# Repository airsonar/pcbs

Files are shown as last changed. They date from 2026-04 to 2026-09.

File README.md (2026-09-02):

<!--
SPDX-FileCopyrightText: AirSonar contributors
SPDX-License-Identifier: CERN-OHL-W-2.0
-->

# AirSonar PCBs

This repository contains designs for PCBs used with the AirSonar project.

## Licensing

The designs and documentation for the circuit boards in this repository are licensed
under the [CERN Open Hardware Licence Version 2 - Weakly Reciprocal][CERNOHL] license
(SPDX code [CERN-OHL-W-2.0][SPDX]). The weakly reciprocal version requires that if you
modify the designs, you release them under an open license. Incorporating the designs
into a larger project does not require that project to be openly licensed (though we
would obviously encourage you to!).

[CERNOHL]: https://gitlab.com/ohwr/project/cernohl/-/wikis/Documents/CERN-OHL-version-2
[SPDX]: https://spdx.org/licenses/CERN-OHL-W-2.0.html

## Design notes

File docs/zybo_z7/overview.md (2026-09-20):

---
SPDX-FileCopyrightText: AirSonar contributors
SPDX-License-Identifier: CERN-OHL-W-2.0
---

# Zybo Z7 ARM/FPGA development board

The [Digilent Zybo Z7][zybo-z7] is a development board based around the [AMD (formerly
Xilinx) Zynq-7000][zynq-7000] system-on-a-chip (SoC). The Zynq-7000 combines a dual-core
ARM Cortex-A9 processor with a Artix-7 FPGA logic. These communicate over standard
[AXI][] communication buses, allowing custom peripherals to be designed in the
programmable logic to communicate with the processor. For the AirSonar project, this
allows many PDM microphones to be simultaneously handled in programmable logic with the
captured data being transferred to processor memory for subsequent processing and
transfer to the client.

The development board contains a number of peripherals, including gigabit Ethernet and a
Analog Devices SSM2603 audio codec outputting to a standard 3.5mm audio jack. It also
has a number of [Pmod connectors][Pmod] allowing custom circuits to be connected to the
development board.

Note that there are two variants of the Zybo Z7, the -10 and -20. These correspond to
different variants of the Zync-700, and the -10 variant has one fewer PMOD connector.
The designs in this repository are tested with the -20 variant but should be usable with
the -10.

[AXI]: https://en.wikipedia.org/wiki/Advanced_eXtensible_Interface
[Pmod]: https://en.wikipedia.org/wiki/Pmod_Interface
[zybo-z7]: https://digilent.com/reference/programmable-logic/zybo-z7/start
[zynq-7000]: https://www.amd.com/en/products/adaptive-socs-and-fpgas/soc/zynq-7000.html

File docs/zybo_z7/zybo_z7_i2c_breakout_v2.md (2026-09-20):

---
SPDX-FileCopyrightText: AirSonar contributors
SPDX-License-Identifier: CERN-OHL-W-2.0
---

# Zybo Z7 I2C breakout (v2)

The JF Pmod connector (at the left edge of the Zybo Z7 when looking at the top) connects
to a number of GPIO lines from the ARM processor. This includes two [I2C][]
communication buses, I2C0 and I2C1. This PCB acts as a breakout board to connect a
number of devices to each bus.

There are four 4-pin IDC connectors (each with 3.3V, ground, clock and data lines)
connected to I2C0. As marked on the silkscreen, these are intended for communicating
with motor drivers. There are ten 4-pin connectors connected to I2C1, intended for
auxiliary sensors such as temperature sensors. Note that the actual use of the two buses
depend on the software running on the processor; the labels on the silkscreen are only
indicative of the original intent when the circuit was designed.

As the Zynq-7000 I2C lines are only rated to 3.3V, both sets of clock and data lines
have Schottky diodes for overvoltage protection if the connected devices use higher
voltages. The design also includes a power LED and a 2x6 surface mount IDC connector
which duplicates the Pmod layout allowing for testing or further development with other
GPIO lines.

[I2C]: https://en.wikipedia.org/wiki/I2C

## Design

The schematic and PCB layout were performed using the [KiCad][] design suite. If you
want the design files, it is recommended you clone the Git repository and access them
from there. A copy of the design files and associated libraries, templates etc as they
were when this documentation was built can be
```genzip
output: airsonar_zybo_z7_i2c_breakout_v2.zip
link_text: downloaded as a zipfile
%%%
directory: libraries
directory: templates
file: zybo_z7/i2c_breakout_v2/zybo_z7_i2c_breakout_v2.kicad_pro
file: zybo_z7/i2c_breakout_v2/zybo_z7_i2c_breakout_v2.kicad_sch
file: zybo_z7/i2c_breakout_v2/zybo_z7_i2c_breakout_v2.kicad_pcb
file: zybo_z7/i2c_breakout_v2/fp-lib-table
file: zybo_z7/i2c_breakout_v2/sym-lib-table
file: zybo_z7/i2c_breakout_v2/REUSE.toml
```
if you prefer.

A
```kipdf
output: airsonar_zybo_z7_i2c_breakout_v2.pdf
link_text: PDF of the schematics and PCB layout
%%%
source: zybo_z7/i2c_breakout_v2/zybo_z7_i2c_breakout_v2.kicad_sch
--no-background-color
%%%
source: zybo_z7/i2c_breakout_v2/zybo_z7_i2c_breakout_v2.kicad_pcb
--layers
F.Cu,F.Silkscreen,Edge.Cuts
--scale
0
%%%
source: zybo_z7/i2c_breakout_v2/zybo_z7_i2c_breakout_v2.kicad_pcb
--layers
B.Cu,B.Silkscreen,Edge.Cuts
--scale
0
```
is also available. Again, this is the status of the design when this documentation was
built. The first page contains the schematic, the second page the copper and silkscreen
for the top layer, and the third page the copper and silkscreen for the bottom layer.

### Bill of materials

The following table lists the components needed to fully populate a single copy of the
PCB.  The prices given are to purchase the exact quantity needed for one PCB from
DigiKey (using the German storefront) as of 20 September 2026. Prices at other suppliers
will differ, using other component variants will change the cost, and buying larger
quantities will typically reduce the unit cost. Note that the cost of the ribbon cable
and IDC crimp connectors is not included.

Component | Description                      | Quantity | Cost
----------|----------------------------------|----------|------
C1        | 10µF 0603 ceramic capacitor      | 1        | [€0.33][dkc1]
C2-C14    | 100nF 0603 ceramic capacitor     | 13       | [€0.38][dkc2]
D1        | Orange LED (0603 package)        | 1        | [€0.21][dkd1]
D2-D5     | Schottky diode                   | 4        | [€0.84][dkd2]
J1-J14    | Through-hole 2x2 IDC header      | 14       | [€8.86][dkj1]
JF1       | Right-angle 2x6 edge connector   | 1        | [€0.92][dkjf1]
JF2       | Surface-mount 2x6 IDC header     | 1        | [€2.88][dkjf2]
R1        | 330Ω 0603 resistor               | 1        | [€0.10][dkr1]
R2-R5     | 33Ω 1/3W 0603 resistor           | 4        | [€0.52][dkr2]
          | **Total**                        |          | €15.04

[dkc1]: https://www.digikey.de/de/products/detail/cal-chip-electronics-inc/GMC10X5R106M25NT/18151144
[dkc2]: https://www.digikey.de/de/products/detail/samsung-electro-mechanics/CL10B104KB8NNND/22313108
[dkd1]: https://www.digikey.de/de/products/detail/harvatek-corporation/B1931UD-05D000314U1930/15861266
[dkd2]: https://www.digikey.de/en/products/detail/onsemi/BAT43XV2/2241875
[dkj1]: https://www.digikey.de/en/products/detail/amphenol-cs-fci/75869-130LF/1523859
[dkjf1]: https://www.digikey.de/en/products/detail/amphenol-cs-fci/10129382-912002BLF/7916140
[dkjf2]: https://www.digikey.de/de/products/detail/samtec-inc/HTST-106-01-L-DV/8473802
[dkr1]: https://www.digikey.de/de/products/detail/te-connectivity-passive-product/CRGH0603F330R/5586961
[dkr2]: https://www.digikey.de/en/products/detail/rohm-semiconductor/ESR03EZPJ330/1983466

<!-- component and software links -->

[KiCad]: https://www.kicad.org/

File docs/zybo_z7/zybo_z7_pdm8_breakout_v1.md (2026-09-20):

---
SPDX-FileCopyrightText: AirSonar contributors
SPDX-License-Identifier: CERN-OHL-W-2.0
---

# Zybo Z7 PDM8 microphone array breakout (v1)

The Pmod connectors at the bottom of the Zybo Z7 (when viewed from the top side) connect
to various IO lines from the FPGA part of the Zynq-7000. These allow custom hardware to
be connected to the FPGA. This PCB acts as a breakout board to connect multiple [PDM8
microphone arrays](../microphone_array/airsonar_pdm8_v1.md) to the FPGA.

When connected to a Zybo Z7-20 variant, up to eight microphone arrays can be connected.
These are configured in a dual-edge mode with two microphones connected to each FPGA IO
pin, outputting data on alternate clock edges. One of the FPGA IO lines is used to
provide the clock to the microphones, leaving 31 pins available for input and thus a
maximum of 62 microphones can be read. The Zybo Z7-10 variant does not include the JB
Pmod connector. This reduces the available input pins to 23 for a maximum of 46
microphones.

The breakout includes a [LMK1C1108PWR][] clock buffer to duplicate the clock signal for
each connector. This avoids adding too much load to the FPGA IO providing the clock.

The breakout also includes a power LED and duplicates of each Pmod connector for
debugging or further development.

!!! Warning
    The connector footprint for the Pmod duplicates (the bottom row of connectors) is
    the same footprint as for the array connectors. However, it is not pin compatible
    with the array connectors; plugging a microphone array into the Pmod duplicate will
    short the power supply. Although the Zybo Z7 appears to handle and recover from
    this, it is recommended that these connectors only be populated if needed, or that a
    different style of connector is used to avoid accidental connections.

## Design

The schematic and PCB layout were performed using the [KiCad][] design suite. If you
want the design files, it is recommended you clone the Git repository and access them
from there. A copy of the design files and associated libraries, templates etc as they
were when this documentation was built can be
```genzip
output: airsonar_zybo_z7_pdm8_breakout_v1.zip
link_text: downloaded as a zipfile
%%%
directory: libraries
directory: templates
file: zybo_z7/pdm8_breakout_v1/zybo_z7_pdm8_breakout_v1.kicad_dru
file: zybo_z7/pdm8_breakout_v1/zybo_z7_pdm8_breakout_v1.kicad_pro
file: zybo_z7/pdm8_breakout_v1/zybo_z7_pdm8_breakout_v1.kicad_sch
file: zybo_z7/pdm8_breakout_v1/zybo_z7_pdm8_breakout_v1.kicad_pcb
file: zybo_z7/pdm8_breakout_v1/fp-lib-table
file: zybo_z7/pdm8_breakout_v1/sym-lib-table
file: zybo_z7/pdm8_breakout_v1/REUSE.toml
```
if you prefer.

A
```kipdf
output: airsonar_zybo_z7_pdm8_breakout_v1.pdf
link_text: PDF of the schematics and PCB layout
%%%
source: zybo_z7/pdm8_breakout_v1/zybo_z7_pdm8_breakout_v1.kicad_sch
--no-background-color
%%%
source: zybo_z7/pdm8_breakout_v1/zybo_z7_pdm8_breakout_v1.kicad_pcb
--layers
F.Cu,F.Silkscreen,Edge.Cuts
--scale
0
%%%
source: zybo_z7/pdm8_breakout_v1/zybo_z7_pdm8_breakout_v1.kicad_pcb
--layers
B.Cu,B.Silkscreen,Edge.Cuts
--scale
0
```
is also available. Again, this is the status of the design when this documentation was
built. The first page contains the schematic, the second page the copper and silkscreen
for the top layer, and the third page the copper and silkscreen for the bottom layer.

### Bill of materials

The following table lists the components needed to fully populate a single copy of the
PCB.  The prices given are to purchase the exact quantity needed for one PCB from
DigiKey (using the German storefront) as of 20 September 2026. Prices at other suppliers
will differ, using other component variants will change the cost, and buying larger
quantities will typically reduce the unit cost. Note that the cost of the ribbon cable
and IDC crimp connectors is not included.

Component                     | Description                      | Quantity | Cost
------------------------------|----------------------------------|----------|------
C1-C3, C5, C7, ..., C33       | 100nF 0603 ceramic capacitor     | 19       | [€0.55][dkc1]
C4, C6, ..., C32              | 10µF 0603 ceramic capacitor      | 16       | [€3.09][dkc4]
D1                            | Orange LED (0603 package)        | 1        | [€0.21][dkd1]
JB1-JE1                       | Right-angle 2x6 edge connector   | 4        | [€3.68][dkjb1]
JB2-JE2, JMA1-JMA4, JMB1-JMB4 | Surface-mount 2x6 IDC header     | 12       | [€29.34][dkjb2]
R1                            | 10kΩ 0603 resistor               | 1        | [€0.09][dkr1]
R2                            | 330Ω 0603 resistor               | 1        | [€0.10][dkr2]
U1                            | [LMK1C1108PWR][] clock buffer    | 1        | [€4.44][dku1]
                              | **Total**                        |          | €41.50

[dkc1]: https://www.digikey.de/de/products/detail/samsung-electro-mechanics/CL10B104KB8NNND/22313108
[dkc4]: https://www.digikey.de/de/products/detail/cal-chip-electronics-inc/GMC10X5R106M25NT/18151144
[dkd1]: https://www.digikey.de/de/products/detail/harvatek-corporation/B1931UD-05D000314U1930/15861266
[dkjb1]: https://www.digikey.de/en/products/detail/amphenol-cs-fci/10129382-912002BLF/7916140
[dkjb2]: https://www.digikey.de/de/products/detail/samtec-inc/HTST-106-01-L-DV/8473802
[dkr1]: https://www.digikey.de/de/products/detail/te-connectivity-passive-product/CRGH0603J10K/2385379
[dkr2]: https://www.digikey.de/de/products/detail/te-connectivity-passive-product/CRGH0603F330R/5586961
[dku1]: https://www.digikey.de/de/products/detail/texas-instruments/LMK1C1108PWR/13627117

## Array configuration

The connectors provide the 3.3V power supply from the Zybo Z7 to the microphones, and
the FPGA expected a 3.3V data signal from the microphones. The 3.3V variant of the
low-dropout regulator may still be used for additional power supply isolation as the
voltage drop is not large enough to cause problems. Alternatively, the regulator can be
removed and bypassed with the corresponding solder jumper on the array PCB.

The upper row of array connectors (labelled ROW A on the silkscreen) set the SEL
(select) line to ground, corresponding to data output on the rising edge. The lower row
of array connectors (ROW B on the silkscreen) sets the SEL line to 3.3V, corresponding
to data output on the falling edge. The microphone arrays should be configured through
the solder jumpers to use the SEL line from the connector. This ensures the output mode
of the microphones to be determined by which breakout connector they are connected to.

## FPGA IO pins

The following table lists the IO connections to the Zybo Z7 for each microphone line.
The first entry in each cell is the Pmod connector pin the microphone is connected to,
and the second entry is the FPGA IO pin it is connected to.

Microphone | Board 1    | Board 2    | Board 3       | Board 4
-----------|------------|------------|---------------|-----------
    0      | JE4 / H15  | JD4 / R14  | Not connected | JB4 / V7
    1      | JE10 / Y17 | JD10 / V18 | JC10 / U12    | JB10 / W6
    2      | JE3 / J15  | JD3 / P14  | JC3 / T11     | JB3 / U7
    3      | JE9 / T17  | JD9 / V17  | JC9 / T12     | JB9 / V6
    4      | JE2 / W16  | JD2 / T15  | JC2 / W15     | JB2 / W8
    5      | JE8 / U17  | JD8 / U15  | JC8 / Y14     | JB8 / Y6
    6      | JE1 / V12  | JD1 / T14  | JC1 / V15     | JB1 / V8
    7      | JE7 / V13  | JD7 / U14  | JC7 / W14     | JB7 / Y7

<!-- component and software links -->

[KiCad]: https://www.kicad.org/
[LMK1C1108PWR]: https://www.ti.com/product/de-de/LMK1C1108/part-details/LMK1C1108PWR

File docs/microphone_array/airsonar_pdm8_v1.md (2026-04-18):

---
SPDX-FileCopyrightText: AirSonar contributors
SPDX-License-Identifier: CERN-OHL-W-2.0
---

# 8-channel PDM microphone array (v1)

This is the first microphone array designed for the AirSonar project. It is based around
eight Syntiant[^knowles] [SPG08P4HM4H MEMS microphones][SPG08P4HM4H] arranged in a
linear array. The centre-to-centre spacing of the microphones is 8.5mm, approximately
half a wavelength at 20kHz in air. The microphones digitise the recorded pressure using
a single-bit [sigma-delta modulator][] to generate a [pulse-density modulated
(PDM)][PDM] output. The array is designed to be connected via a 12-pin ribbon cable, and
includes a [LMK1C1108PWR][] clock buffer to drive the microphones from a single input
clock and a [MAX8891][] linear regulator to control the supply voltage.

[^knowles]: Syntiant purchased the consumer MEMS microphones section of Knowles at the
    end of 2024. Some sources may still refer to these microphones as a Knowles product.

[sigma-delta modulator]: https://en.wikipedia.org/wiki/Delta-sigma_modulation
[PDM]: https://en.wikipedia.org/wiki/Pulse-density_modulation

## Design

The schematic and PCB layout were performed using the [KiCad][] design suite. If you
want the design files, it is recommended you clone the Git repository and access them
from there. A copy of the design files and associated libraries, templates etc as they
were when this documentation was built can be
```genzip
output: airsonar_pdm8_v1.zip
link_text: downloaded as a zipfile
%%%
directory: libraries
directory: templates
file: microphone_array/pdm8_v1/airsonar_pdm8_v1.kicad_pro
file: microphone_array/pdm8_v1/airsonar_pdm8_v1.kicad_sch
file: microphone_array/pdm8_v1/airsonar_pdm8_v1.kicad_pcb
file: microphone_array/pdm8_v1/airsonar_pdm8_v1.kicad_dru
file: microphone_array/pdm8_v1/fp-lib-table
file: microphone_array/pdm8_v1/sym-lib-table
file: microphone_array/pdm8_v1/REUSE.toml
```
if you prefer.

A
```kipdf
output: airsonar_pdm8_v1.pdf
link_text: PDF of the schematics and PCB layout
%%%
source: microphone_array/pdm8_v1/airsonar_pdm8_v1.kicad_sch
--no-background-color
%%%
source: microphone_array/pdm8_v1/airsonar_pdm8_v1.kicad_pcb
--layers
F.Cu,F.Silkscreen,Edge.Cuts
--scale
0
%%%
source: microphone_array/pdm8_v1/airsonar_pdm8_v1.kicad_pcb
--layers
B.Cu,B.Silkscreen,Edge.Cuts
--scale
0
```
is also available. Again, this is the status of the design when this documentation was
built. The first page contains the schematic, the second page the copper and silkscreen
for the top layer, and the third page the copper and silkscreen for the bottom layer.

### Bill of materials

The following table lists the components needed to populate a single copy of the PCB.
The prices given are to purchase the exact quantity needed for one PCB from DigiKey
(using the German storefront) as of 6 April 2026, using the 3.3V variant of the voltage
regulator and an orange LED. Prices at other suppliers will differ, using other
component variants will change the cost, and buying larger quantities will typically
reduce the unit cost.  Note that the cost of the ribbon cable and IDC crimp connectors
is not included.

Component | Description                      | Quantity | Cost
----------|----------------------------------|----------|------
C0-C10    | 100nF 0603 ceramic capacitor     | 11       | [€0.20][dkc0]
C11       | 10µF 0603 ceramic capacitor      | 1        | [€0.23][dkc11]
C12, C13  | 1µF 0603 ceramic capacitor       | 2        | [€0.14][dkc12]
D1        | Orange LED (0603 package)        | 1        | [€0.21][dkd1]
J1        | Surface-mount 2x6 IDC header     | 1        | [€2.67][dkj1]
MK0-MK7   | [SPG08P4HM4H][] MEMS microphone  | 8        | [€12.56][dkmk]
R0-R7     | 0Ω 0603 resistor                 | 8        | [€0.72][dkr0]
R8        | 330Ω 0603 resistor               | 1        | [€0.09][dkr8]
R9        | 10kΩ 0603 resistor               | 1        | [€0.09][dkr9]
U1        | [MAX8891][] linear regulator     | 1        | [€1.61][dku1]
U2        | [LMK1C1108PWR][] clock buffer    | 1        | [€3.25][dku2]
          | **Total**                        |          | €21.77

[dkc0]: https://www.digikey.de/de/products/detail/samsung-electro-mechanics/CL10B104KB8NNWC/3887593
[dkc11]: https://www.digikey.de/de/products/detail/cal-chip-electronics-inc/GMC10X5R106M25NT/18151144
[dkc12]: https://www.digikey.de/de/products/detail/taiyo-yuden/TMK107B7105KA-T/2714177
[dkd1]: https://www.digikey.de/de/products/detail/harvatek-corporation/B1931UD-05D000314U1930/15861266
[dkj1]: https://www.digikey.de/de/products/detail/samtec-inc/HTST-106-01-L-DV/8473802
[dkmk]: https://www.digikey.de/de/products/detail/syntiant/SPG08P4HM4H-1/10130506
[dkr0]: https://www.digikey.de/de/products/detail/walsin-technology-corporation/WR06X000-PTL/5978108
[dkr8]: https://www.digikey.de/de/products/detail/te-connectivity-passive-product/CRGH0603F330R/5586961
[dkr9]: https://www.digikey.de/de/products/detail/te-connectivity-passive-product/CRGH0603J10K/2385379
[dku1]: https://www.digikey.de/de/products/detail/analog-devices-inc-maxim-integrated/MAX8891EXK33-T/10461057
[dku2]: https://www.digikey.de/de/products/detail/texas-instruments/LMK1C1108PWR/13627117

A bill of materials with this particular choice of components can be [downloaded as a
CSV](airsonar_pdm8_v1_bom.csv) and used with your preferred supplier or BOM tool.

### Power budget

The microphones can operate with a supply voltage between 1.65V and 3.6V; the clock
buffer has specifications for supply voltages of 1.8V, 2.5V and 3.3V. The highest
required supply current for any of these voltages has been used for the power budget in
the table below. It is also worth noting that the current required by the clock buffer
depends on the clock frequency. The values in section 6.5 of its datasheet (revision A)
are for a 100MHz clock. The figure in section 6.7 indicates the supply current will be
less than 20mA from a 3.3V supply at 5MHz; this value is used for the power budget. A
current of 5mA has been allowed for the power LED.

| Component | Max current | Quantity | Required current |
|---|:---:|:---:|:---:|
| [SPG08P4HM4H][] microphone | 2 mA | 8 | 16 mA |
| [LMK1C1108PWR][] clock buffer | 20 mA | 1 | 20 mA |
| Power LED | 5 mA | 1 | 5 mA |
| **Total** | | | **41 mA** |

## Configuration

The design has several hardware configuration options for the user. The supply voltage
can be set as needed by selecting the appropriate variant of the voltage regulator, and
a number of solder bridges need to be set to determine how the PDM outputs of the
microphones operate.

### Power supply

The circuit includes a [MAX8891][] low-dropout linear regulator (U1). There are a number
of pin-compatible variants of the regulator with different output voltages. The supply
voltage (Vdd) for the circuit can be between 1.8V and 3.3V.

There are three types of logic signals on the connector: the clock input (routed through
the clock buffer), the select input, and the data outputs. The valid voltages for these
signals are summarised in the following table.

Signal          | Logic low        | Logic high
----------------|------------------|--------------------
Clock (input)   | -0.5V to 0.3Vdd  | 0.7Vdd to 3.6V
Select (input)  | -0.3V to 0.2V    | Vdd - 0.2V to 3.6V
Data (output)   |  0V to 0.45V     | Vdd - 0.45V to Vdd

The inputs are tolerant to 3.6V (preferably 3.3V) regardless of the supply voltage. The
output level is dependent on the supply voltage. As such, the regulator variant should
be selected to ensure the output logic level is compatible with the system reading it.

Alternatively, the regulator can be skipped and the voltage supply from the connecting
cable used to directly power the circuit. To achieve this, do not place the regulator
and use a solder bridge to short JP13.

Note that the regulator has a sufficiently low dropout (approximately 50mV at the 41mA
from the power budget) to be usable with an input voltage that is the same as the
desired supply voltage.

### Microphone select line

The data output from each microphone is driven around one edge of the clock and is high
impedance around the other edge of the clock. The desired output edge is set by the SEL
input (pin 6) to the microphone:

* If SEL = VDD, the data output should be sampled on the falling edge of the clock.
* If SEL = GND, the data output should be sampled on the rising edge of the clock.

The circuit has a number of jumpers (corresponding to solder bridges on the PCB) which
must be set to configure the output edge of each microphone. The eight jumpers JP0
through JP7 configure the corresponding microphone (MK0 through MK7). These can be used
to directly set its microphone SEL line to either VDD or GND as desired. Alternatively,
the jumper can be set to the BSEL line (denoted BOARD on the PCB silkscreen) which
corresponds to a setting for the entire PCB.

This board-level setting is configured by JP8. This can be connected to VDD or GND, or
to the SEL line from the connector (labelled CONNECTOR on the PCB silkscreen). The
latter option allows the edge to use for the board to be configured by setting pin 3 of
the connector cable to VDD or GND as desired. This means that the output edge is
determined by the system that the board is connected to.

!!! Warning
    The microphone datasheet does have a figure (Figure 5 in Rev D-1) which suggests the
    SEL pin can be left unconnected for single-microphone applications (i.e., if not
    multiplexing a stereo pair). It is unclear which clock edge the data line is driven
    on in this case; the voltage may remain long enough to be read on either edge. It is
    recommended that the solder bridges are explicitly set to define the desired edge.

### Output multiplexing

As their data outputs are high-impedance around the unused clock edge, two
microphones using opposite clock edges can be connected to a single data line as a
stereo pair.[^micddr] This can be done at a board level by connecting two PCBs to the
same data lines with one PCB configured to use the rising edge and the other the falling
edge (it is recommended that the CONNECTOR option for the microphone select line is used
in this case to prevent mismatches, with one receiver connector setting SEL to ground
and the other setting it to Vdd).

Alternatively, this multiplexing can be done on a single PCB. The jumpers JP9 through
JP12 each connect the data outputs from two microphones (the pairs are MK0 and MK4, MK1
and MK5, MK2 and MK6, MK3 and MK7). In this case, the connector can be replaced by an
eight-pin connector omitting pins 9-12 of the full connector if desired.

[^micddr]: Note that this requires the system receiving the microphone data to be able
    to handle double data rate (DDR) inputs.

## Usage notes

### Microphone clock speeds

The microphones have three power modes (excluding the powered off state) depending on
the frequency of the supplied clock signal:

* Sleep mode: clock less than 250kHz
* Low power mode: clock between 600kHz and 950kHz
* Normal mode: clock between 1.2MHz and 4.8MHz

Note that there are gaps between these frequency bands in which the mode is undefined.

### Microphone wake-up time

When transitioning from the sleep mode to an active mode, the datasheet specifies a
maximum wake-up time of 20ms (Table 2 of revision D-1). From the same table, the startup
from an unpowered microphone to an active state takes a maximum of 50ms. If putting the
microphones in sleep mode to save power, make sure they are woken up a sufficient time
before you wish to record.

### DC offset

As the microphone is a capacitive sensor, it typically has a DC offset, and this offset
changes over time. The datasheet gives a range of -3.25% to 0.1% of the full-scale
output for the DC offset.

### Microphone polarity

The microphone datasheet states that an increasing sound pressure results in a
decreasing density of 1s in the PDM output stream. If downsampled directly, the waveform
will be inverted from the original pressure wave incident at the microphones. To
correct this, the PDM stream can be bit-inverted on collection or before processing
starts. Alternatively, the final waveform can be negated, but note that the microphone
typically has a drifting DC offset which may complicate this.

<!-- component and software links -->

[KiCad]: https://www.kicad.org/
[MAX8891]: https://www.analog.com/en/products/max8891.html
[LMK1C1108PWR]: https://www.ti.com/product/de-de/LMK1C1108/part-details/LMK1C1108PWR
[SPG08P4HM4H]: https://www.syntiant.com/s/SPG08P4HM4H-1_Baracus_Datasheet_RevD-1.pdf

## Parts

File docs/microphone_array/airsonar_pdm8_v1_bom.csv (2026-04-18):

Part Number | Manufacturer | Description | Quantity
CL10B104KB8NNWC | Samsung Electro-Mechanics | Ceramic Capacitor, Multilayer, Ceramic, 50V, 10% +Tol, 10% -Tol, X7R, +-15% TC, 100nF, Surface Mount, 0603 inch | 11
GMC10X5R106M25NT | Cal-Chip Electronics | Ceramic Capacitor, Multilayer, Ceramic, 25V, 20% +Tol, 20% -Tol, X5R, 15% TC, 10uF, Surface Mount, 0603 | 1
TMK107B7105KA-T | TAIYO YUDEN | 25V 1uF X7R ±10% 0603 Multilayer Ceramic Capacitors MLCC - SMD/SMT ROHS | 1
B1931UD--05D000314U1930 | Harvatek | Led Orange Diffused 0603 SMD | 1
HTST-106-01-L-DV | Samtec | Pin Header, Wire-to-Board, 2.54 mm, 2 Rows, 12 Contacts, Surface Mount, HTST | 1
SPG08P4HM4H-1 | Knowles | Baracus Mic Multimode Dig Top Pt | 8
WR06X000 PTL | Walsin Technologies | Fixed Resistor, Metal Glaze/thick Film, 0.1W, 0ohm, Surface Mount, 0603, CHIP, ROHS COMPLIANT | 8
2176177-5 | TE Connectivity / AMP | Res Thick Film 0603 330 Ohm 1% 0.2W(1/5W) ±100ppm/C Pad SMD T/R | 1
CRGH0603J10K | TE Connectivity | Res Thick Film 0603 10K Ohm 5% 0.2W(1/5W) ±100ppm/C Pad SMD T/R Automotive AEC-Q200 | 1
MAX8891EXK33+T | Analog Devices | Low-Dropout Linear Regulators Designed for Ultra-Low Noise in a SC70 Package | 1
LMK1C1108PWR | Texas Instruments | Clock Buffer 8-channel output LVCMOS 1.8-V buffer 16-TSSOP -40 to 125 | 1

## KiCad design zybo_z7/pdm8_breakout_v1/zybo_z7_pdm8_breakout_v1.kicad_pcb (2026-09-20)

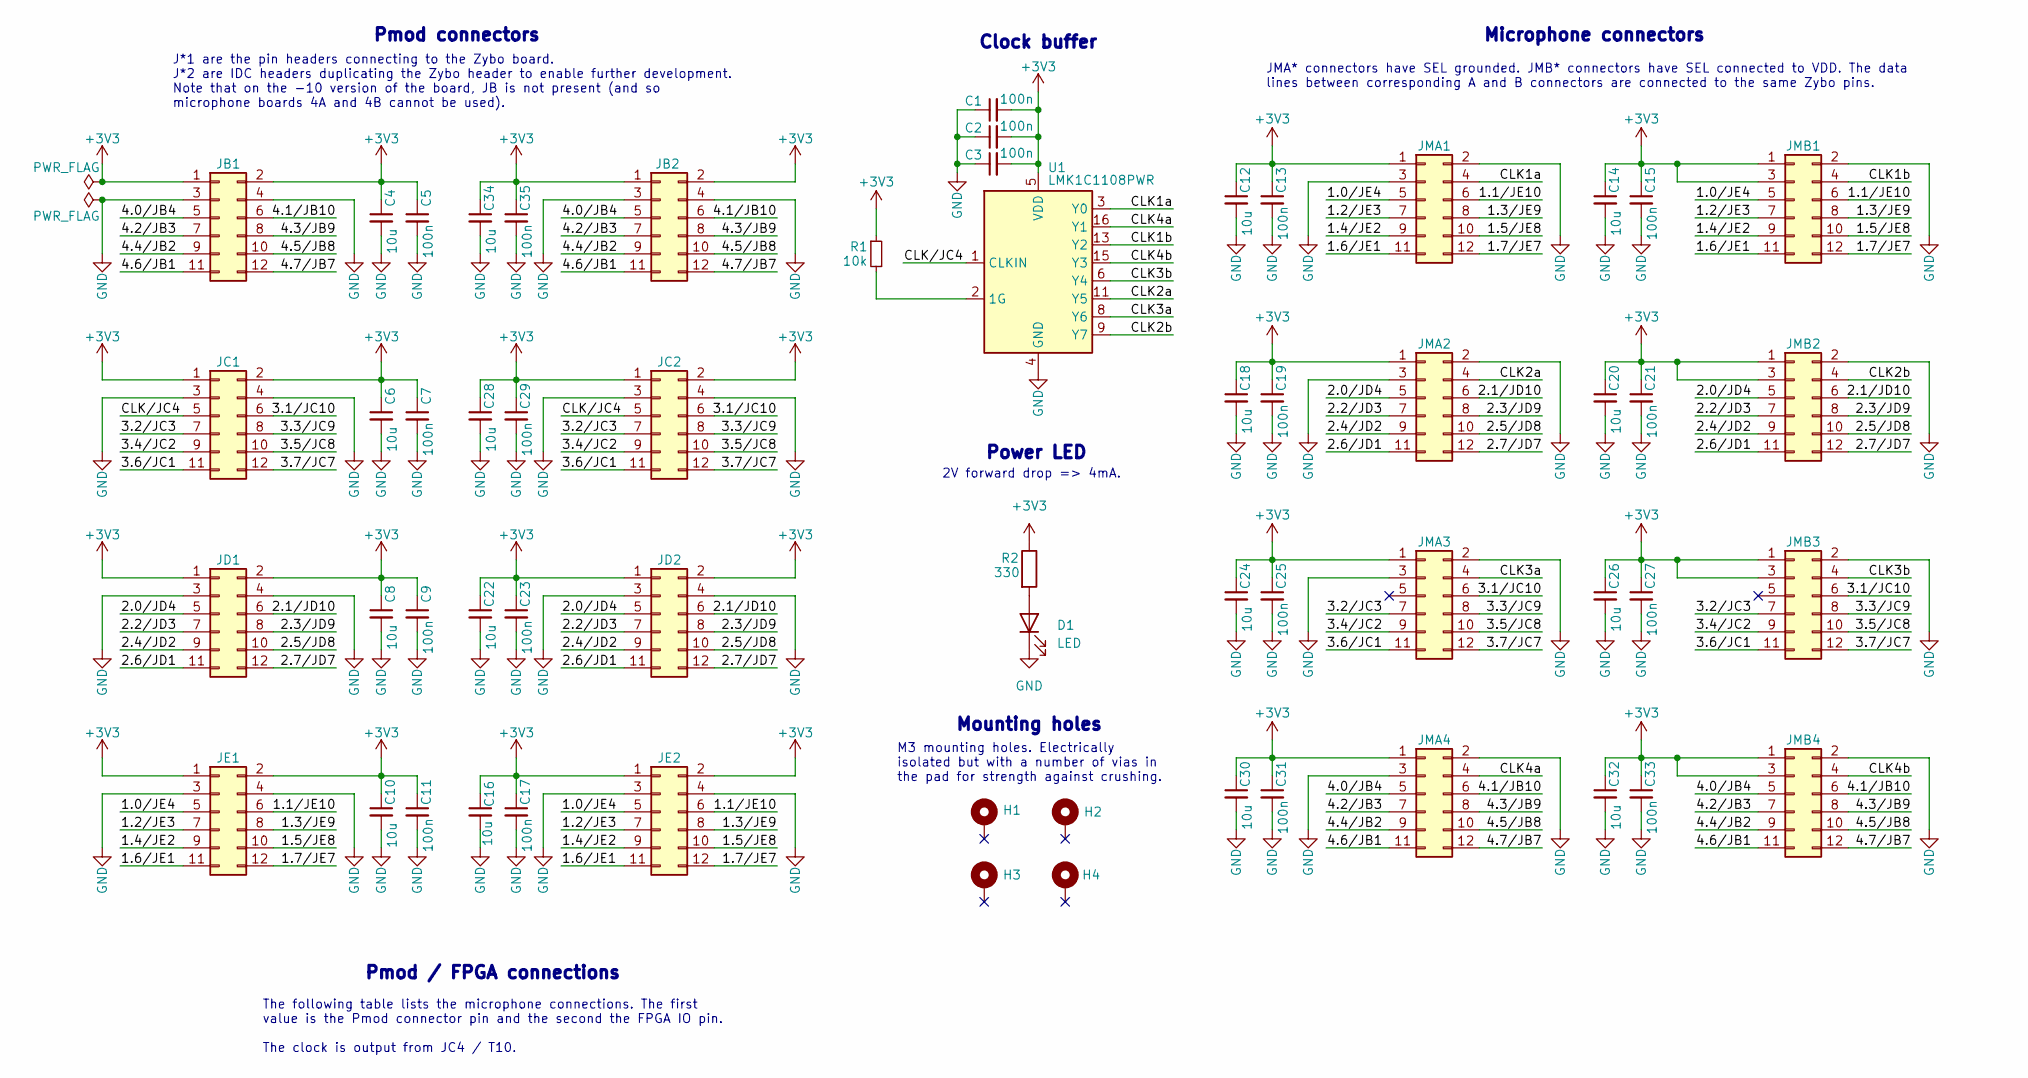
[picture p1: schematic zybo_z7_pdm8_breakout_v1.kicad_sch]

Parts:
C1, C2, C3, C5, C7, C9, C11, C13, C15, C17, C19, C21, C23, C25, C27, C29, C31, C33, C35: 100n; C_0603_1608Metric_Pad1.08x0.95mm_HandSolder
C4, C6, C8, C10, C12, C14, C16, C18, C20, C22, C24, C26, C28, C30, C32, C34: 10u; C_0603_1608Metric_Pad1.08x0.95mm_HandSolder
D1: LED; LED_0603_1608Metric
H1, H2, H3, H4: MountingHole_Pad; MountingHole_3.2mm_M3_Pad_Via
JB1: Conn_02x06_Odd_Even; PinHeader_2x06_P2.54mm_Horizontal
JB2: Conn_02x06_Odd_Even; IDC-Header_2x06_P2.54mm_Vertical_SMD
JC1: Conn_02x06_Odd_Even; PinHeader_2x06_P2.54mm_Horizontal
JC2: Conn_02x06_Odd_Even; IDC-Header_2x06_P2.54mm_Vertical_SMD
JD1: Conn_02x06_Odd_Even; PinHeader_2x06_P2.54mm_Horizontal
JD2: Conn_02x06_Odd_Even; IDC-Header_2x06_P2.54mm_Vertical_SMD
JE1: Conn_02x06_Odd_Even; PinHeader_2x06_P2.54mm_Horizontal
JE2: Conn_02x06_Odd_Even; IDC-Header_2x06_P2.54mm_Vertical_SMD
JMA1, JMA2, JMA3, JMA4: Conn_02x06_Odd_Even; IDC-Header_2x06_P2.54mm_Vertical_SMD
JMB1, JMB2, JMB3, JMB4: Conn_02x06_Odd_Even; IDC-Header_2x06_P2.54mm_Vertical_SMD
R1: 10k; R_0603_1608Metric_Pad0.98x0.95mm_HandSolder
R2: 330; R_0603_1608Metric_Pad0.98x0.95mm_HandSolder
U1: LMK1C1108PWR; TSSOP-16_4.4x5mm_P0.65mm

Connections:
+3V3: C1.2, C2.2, C3.2, C4.1, C5.1, C6.1, C7.1, C8.1, C9.1, C10.1, C11.1, C12.1, C13.1, C14.1, C15.1, C16.1, C17.1, C18.1, C19.1, C20.1, C21.1, C22.1, C23.1, C24.1, C25.1, C26.1, C27.1, C28.1, C29.1, C30.1, C31.1, C32.1, C33.1, C34.1, C35.1, JB1.1, JB1.2, JB2.1, JB2.2, JC1.1, JC1.2, JC2.1, JC2.2, JD1.1, JD1.2, JD2.1, JD2.2, JE1.1, JE1.2, JE2.1, JE2.2, JMA1.1, JMA2.1, JMA3.1, JMA4.1, JMB1.1, JMB1.3, JMB2.1, JMB2.3, JMB3.1, JMB3.3, JMB4.1, JMB4.3, R1.1, R2.1, U1.5 (VDD), U1.10 (VDD), U1.14 (VDD)
/1.0/JE4: JE1.5, JE2.5, JMA1.5, JMB1.5
/1.1/JE10: JE1.6, JE2.6, JMA1.6, JMB1.6
/1.2/JE3: JE1.7, JE2.7, JMA1.7, JMB1.7
/1.3/JE9: JE1.8, JE2.8, JMA1.8, JMB1.8
/1.4/JE2: JE1.9, JE2.9, JMA1.9, JMB1.9
/1.5/JE8: JE1.10, JE2.10, JMA1.10, JMB1.10
/1.6/JE1: JE1.11, JE2.11, JMA1.11, JMB1.11
/1.7/JE7: JE1.12, JE2.12, JMA1.12, JMB1.12
/2.0/JD4: JD1.5, JD2.5, JMA2.5, JMB2.5
/2.1/JD10: JD1.6, JD2.6, JMA2.6, JMB2.6
/2.2/JD3: JD1.7, JD2.7, JMA2.7, JMB2.7
/2.3/JD9: JD1.8, JD2.8, JMA2.8, JMB2.8
/2.4/JD2: JD1.9, JD2.9, JMA2.9, JMB2.9
/2.5/JD8: JD1.10, JD2.10, JMA2.10, JMB2.10
/2.6/JD1: JD1.11, JD2.11, JMA2.11, JMB2.11
/2.7/JD7: JD1.12, JD2.12, JMA2.12, JMB2.12
/3.1/JC10: JC1.6, JC2.6, JMA3.6, JMB3.6
/3.2/JC3: JC1.7, JC2.7, JMA3.7, JMB3.7
/3.3/JC9: JC1.8, JC2.8, JMA3.8, JMB3.8
/3.4/JC2: JC1.9, JC2.9, JMA3.9, JMB3.9
/3.5/JC8: JC1.10, JC2.10, JMA3.10, JMB3.10
/3.6/JC1: JC1.11, JC2.11, JMA3.11, JMB3.11
/3.7/JC7: JC1.12, JC2.12, JMA3.12, JMB3.12
/4.0/JB4: JB1.5, JB2.5, JMA4.5, JMB4.5
/4.1/JB10: JB1.6, JB2.6, JMA4.6, JMB4.6
/4.2/JB3: JB1.7, JB2.7, JMA4.7, JMB4.7
/4.3/JB9: JB1.8, JB2.8, JMA4.8, JMB4.8
/4.4/JB2: JB1.9, JB2.9, JMA4.9, JMB4.9
/4.5/JB8: JB1.10, JB2.10, JMA4.10, JMB4.10
/4.6/JB1: JB1.11, JB2.11, JMA4.11, JMB4.11
/4.7/JB7: JB1.12, JB2.12, JMA4.12, JMB4.12
/CLK1a: JMA1.4, U1.3 (Y0)
/CLK1b: JMB1.4, U1.13 (Y2)
/CLK2a: JMA2.4, U1.11 (Y5)
/CLK2b: JMB2.4, U1.9 (Y7)
/CLK3a: JMA3.4, U1.8 (Y6)
/CLK3b: JMB3.4, U1.6 (Y4)
/CLK4a: JMA4.4, U1.16 (Y1)
/CLK4b: JMB4.4, U1.15 (Y3)
/CLK/JC4: JC1.5, JC2.5, U1.1 (CLKIN)
GND: C1.1, C2.1, C3.1, C4.2, C5.2, C6.2, C7.2, C8.2, C9.2, C10.2, C11.2, C12.2, C13.2, C14.2, C15.2, C16.2, C17.2, C18.2, C19.2, C20.2, C21.2, C22.2, C23.2, C24.2, C25.2, C26.2, C27.2, C28.2, C29.2, C30.2, C31.2, C32.2, C33.2, C34.2, C35.2, D1.1 (K), JB1.3, JB1.4, JB2.3, JB2.4, JC1.3, JC1.4, JC2.3, JC2.4, JD1.3, JD1.4, JD2.3, JD2.4, JE1.3, JE1.4, JE2.3, JE2.4, JMA1.2, JMA1.3, JMA2.2, JMA2.3, JMA3.2, JMA3.3, JMA4.2, JMA4.3, JMB1.2, JMB2.2, JMB3.2, JMB4.2, U1.4 (GND), U1.7 (GND), U1.12 (GND)
unnamed: D1.2 (A), R2.2
unnamed: R1.2, U1.2 (1G)

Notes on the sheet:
Clock buffer
Microphone connectors
Mounting holes
Power LED
Pmod connectors
Pmod / FPGA connections
JMA* connectors have SEL grounded. JMB* connectors have SEL connected to VDD. The data lines between corresponding A and B connectors are connected to the same Zybo pins.
M3 mounting holes. Electrically isolated but with a number of vias in the pad for strength against crushing.
J*1 are the pin headers connecting to the Zybo board. J*2 are IDC headers duplicating the Zybo header to enable further development. Note that on the -10 version of the board, JB is not present (and so microphone boards 4A and 4B cannot be used).
2V forward drop => 4mA.
The following table lists the microphone connections. The first value is the Pmod connector pin and the second the FPGA IO pin. The clock is output from JC4 / T10.

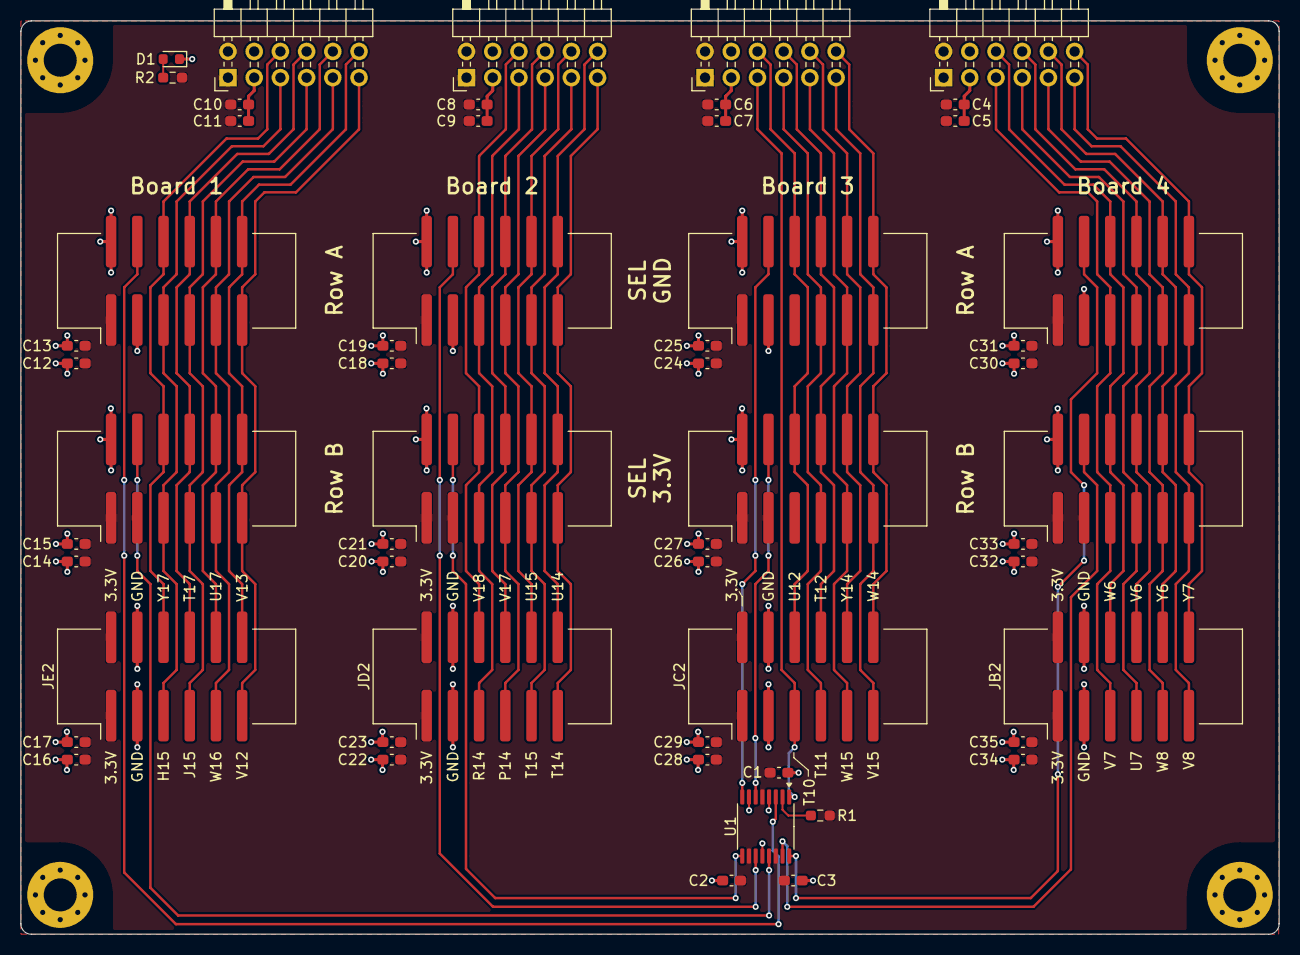
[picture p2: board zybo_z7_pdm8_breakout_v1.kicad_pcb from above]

Board: 2 copper layers, 121.9 x 88.5 mm, 59 parts (0 on the bottom side), 44 nets.

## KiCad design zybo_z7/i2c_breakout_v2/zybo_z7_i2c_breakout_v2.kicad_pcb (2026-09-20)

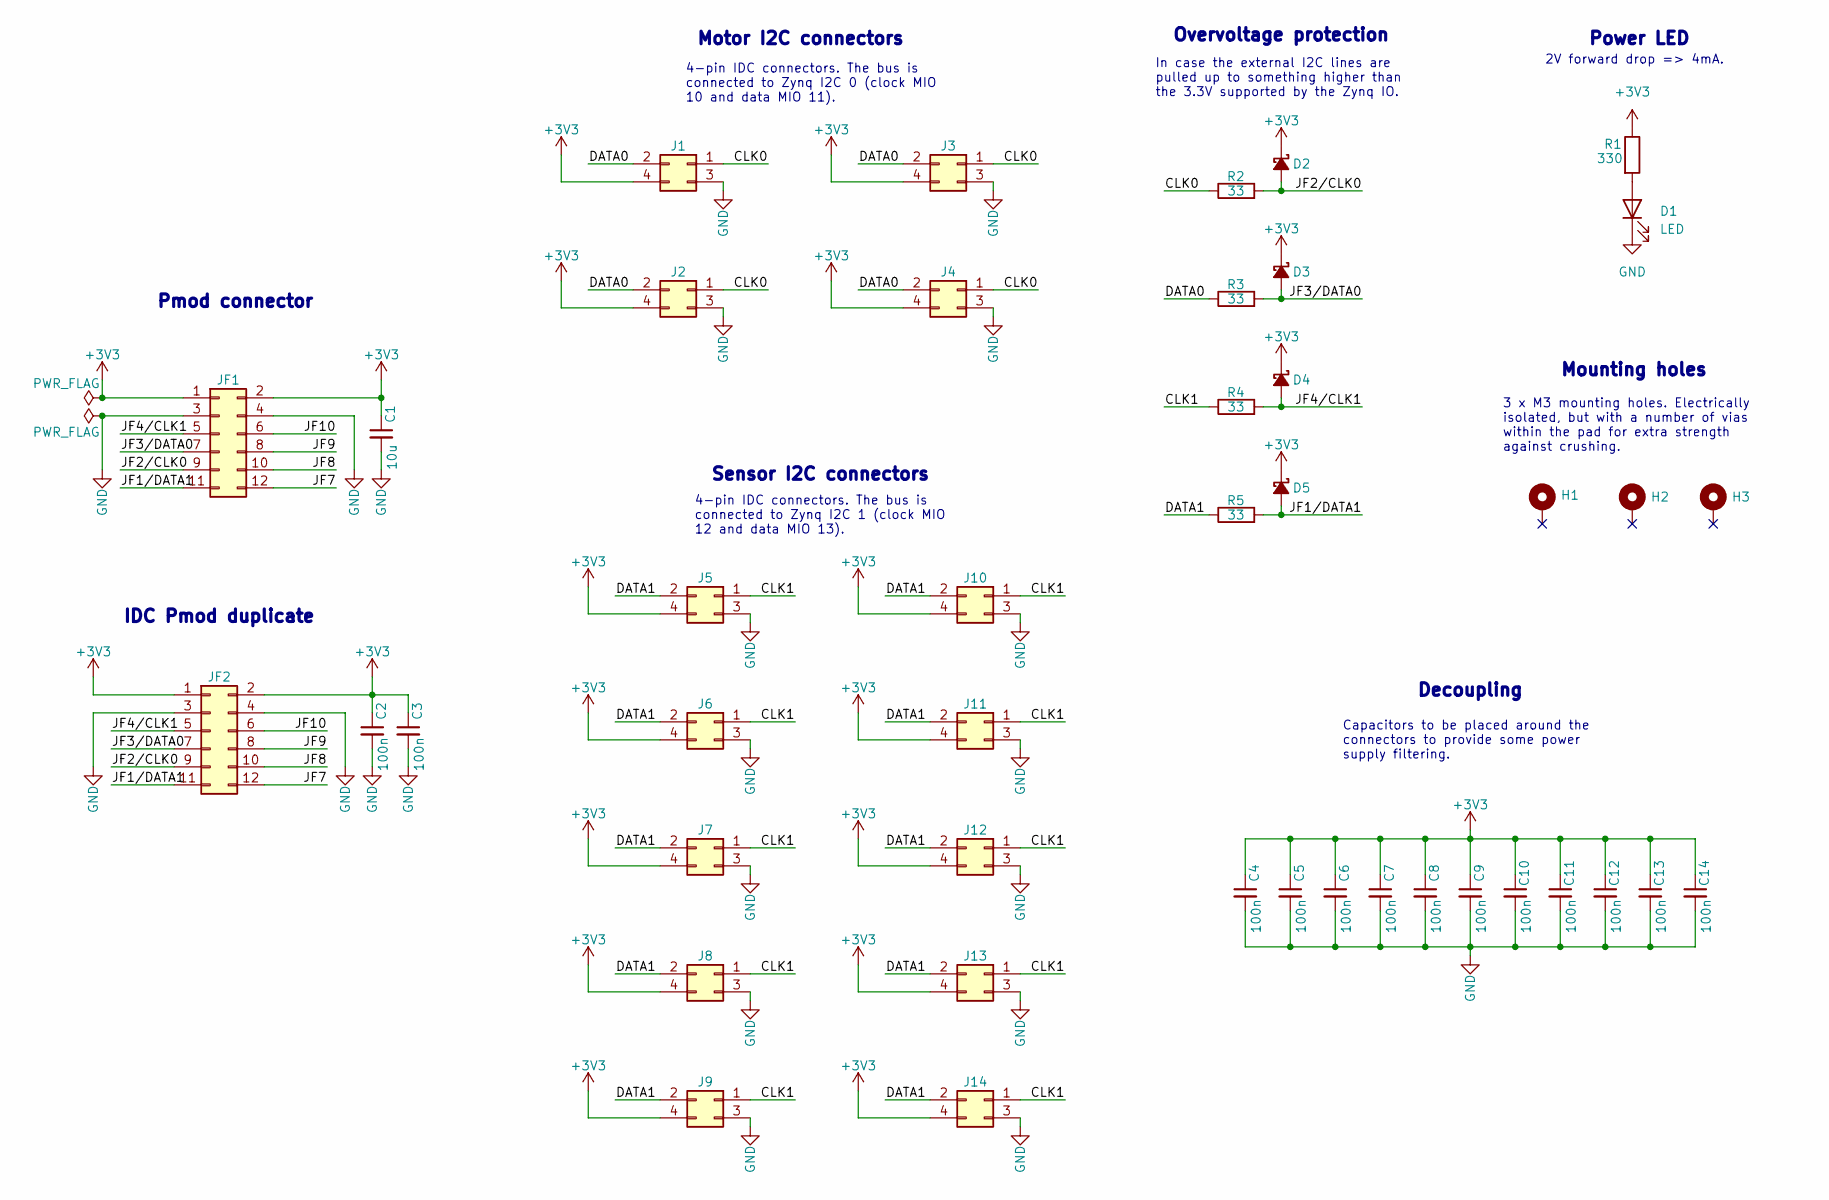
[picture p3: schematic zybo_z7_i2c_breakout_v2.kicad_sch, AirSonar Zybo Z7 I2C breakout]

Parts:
C1: 10u; C_0603_1608Metric_Pad1.08x0.95mm_HandSolder
C2, C3, C4, C5, C6, C7, C8, C9, C10, C11, C12, C13, C14: 100n; C_0603_1608Metric_Pad1.08x0.95mm_HandSolder
D1: LED; LED_0603_1608Metric
D2, D3, D4, D5: D_Schottky_Small_Filled; D_SOD-523
H1, H2, H3: MountingHole_Pad; MountingHole_3.2mm_M3_Pad_Via
J1, J2, J3, J4, J5, J6, J7, J8, J9, J10, J11, J12, J13, J14: Conn_02x02_Odd_Even; Amphenol_75869-130LF
JF1: Conn_02x06_Odd_Even; PinHeader_2x06_P2.54mm_Horizontal
JF2: Conn_02x06_Odd_Even; IDC-Header_2x06_P2.54mm_Vertical_SMD
R1: 330; R_0603_1608Metric_Pad0.98x0.95mm_HandSolder
R2, R3, R4, R5: 33; R_0603_1608Metric_Pad0.98x0.95mm_HandSolder

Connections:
+3V3: C1.1, C2.1, C3.1, C4.1, C5.1, C6.1, C7.1, C8.1, C9.1, C10.1, C11.1, C12.1, C13.1, C14.1, D2.1 (K), D3.1 (K), D4.1 (K), D5.1 (K), J1.4, J2.4, J3.4, J4.4, J5.4, J6.4, J7.4, J8.4, J9.4, J10.4, J11.4, J12.4, J13.4, J14.4, JF1.1, JF1.2, JF2.1, JF2.2, R1.1
/CLK0: J1.1, J2.1, J3.1, J4.1, R2.1
/CLK1: J5.1, J6.1, J7.1, J8.1, J9.1, J10.1, J11.1, J12.1, J13.1, J14.1, R4.1
/DATA0: J1.2, J2.2, J3.2, J4.2, R3.1
/DATA1: J5.2, J6.2, J7.2, J8.2, J9.2, J10.2, J11.2, J12.2, J13.2, J14.2, R5.1
/JF1/DATA1: D5.2 (A), JF1.11, JF2.11, R5.2
/JF2/CLK0: D2.2 (A), JF1.9, JF2.9, R2.2
/JF3/DATA0: D3.2 (A), JF1.7, JF2.7, R3.2
/JF4/CLK1: D4.2 (A), JF1.5, JF2.5, R4.2
/JF7: JF1.12, JF2.12
/JF8: JF1.10, JF2.10
/JF9: JF1.8, JF2.8
/JF10: JF1.6, JF2.6
GND: C1.2, C2.2, C3.2, C4.2, C5.2, C6.2, C7.2, C8.2, C9.2, C10.2, C11.2, C12.2, C13.2, C14.2, D1.1 (K), J1.3, J2.3, J3.3, J4.3, J5.3, J6.3, J7.3, J8.3, J9.3, J10.3, J11.3, J12.3, J13.3, J14.3, JF1.3, JF1.4, JF2.3, JF2.4
unnamed: D1.2 (A), R1.2

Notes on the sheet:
Sensor I2C connectors
Motor I2C connectors
Overvoltage protection
Pmod connector
Power LED
IDC Pmod duplicate
Mounting holes
Decoupling
4-pin IDC connectors. The bus is connected to Zynq I2C 0 (clock MIO 10 and data MIO 11).
4-pin IDC connectors. The bus is connected to Zynq I2C 1 (clock MIO 12 and data MIO 13).
Capacitors to be placed around the connectors to provide some power supply filtering.
2V forward drop => 4mA.
3 x M3 mounting holes. Electrically isolated, but with a number of vias within the pad for extra strength against crushing.
In case the external I2C lines are pulled up to something higher than the 3.3V supported by the Zynq IO.

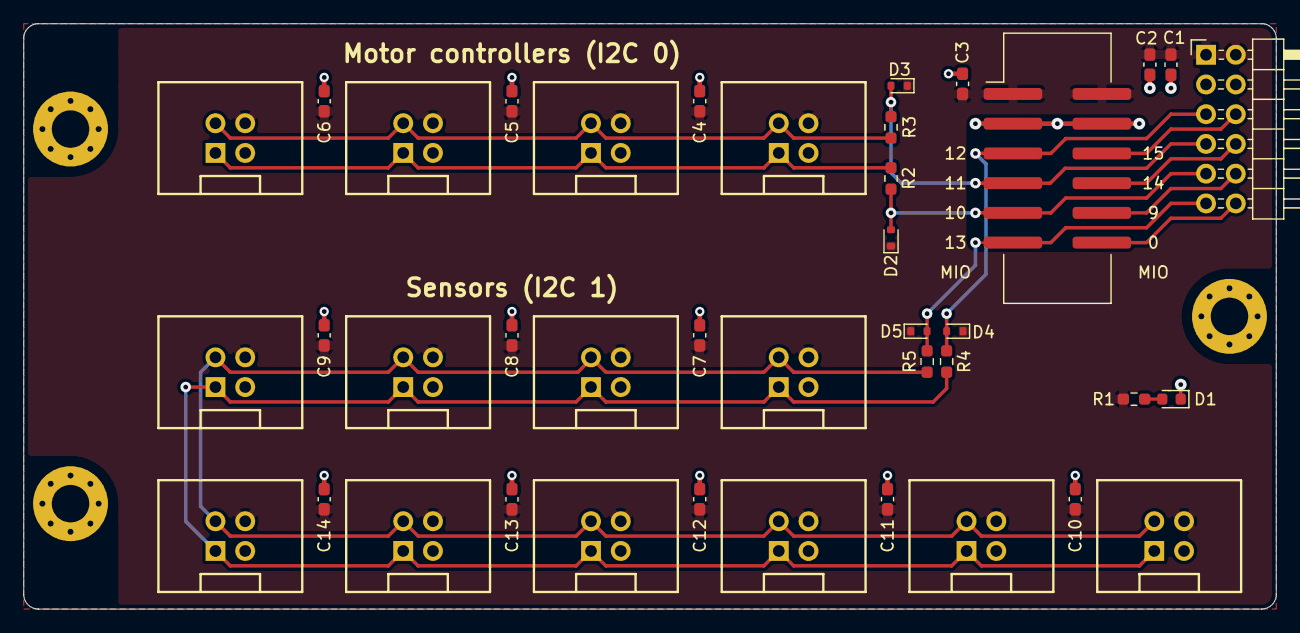
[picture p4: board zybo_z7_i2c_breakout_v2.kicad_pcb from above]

Board: 2 copper layers, 107.0 x 50.0 mm, 43 parts (0 on the bottom side), 15 nets.

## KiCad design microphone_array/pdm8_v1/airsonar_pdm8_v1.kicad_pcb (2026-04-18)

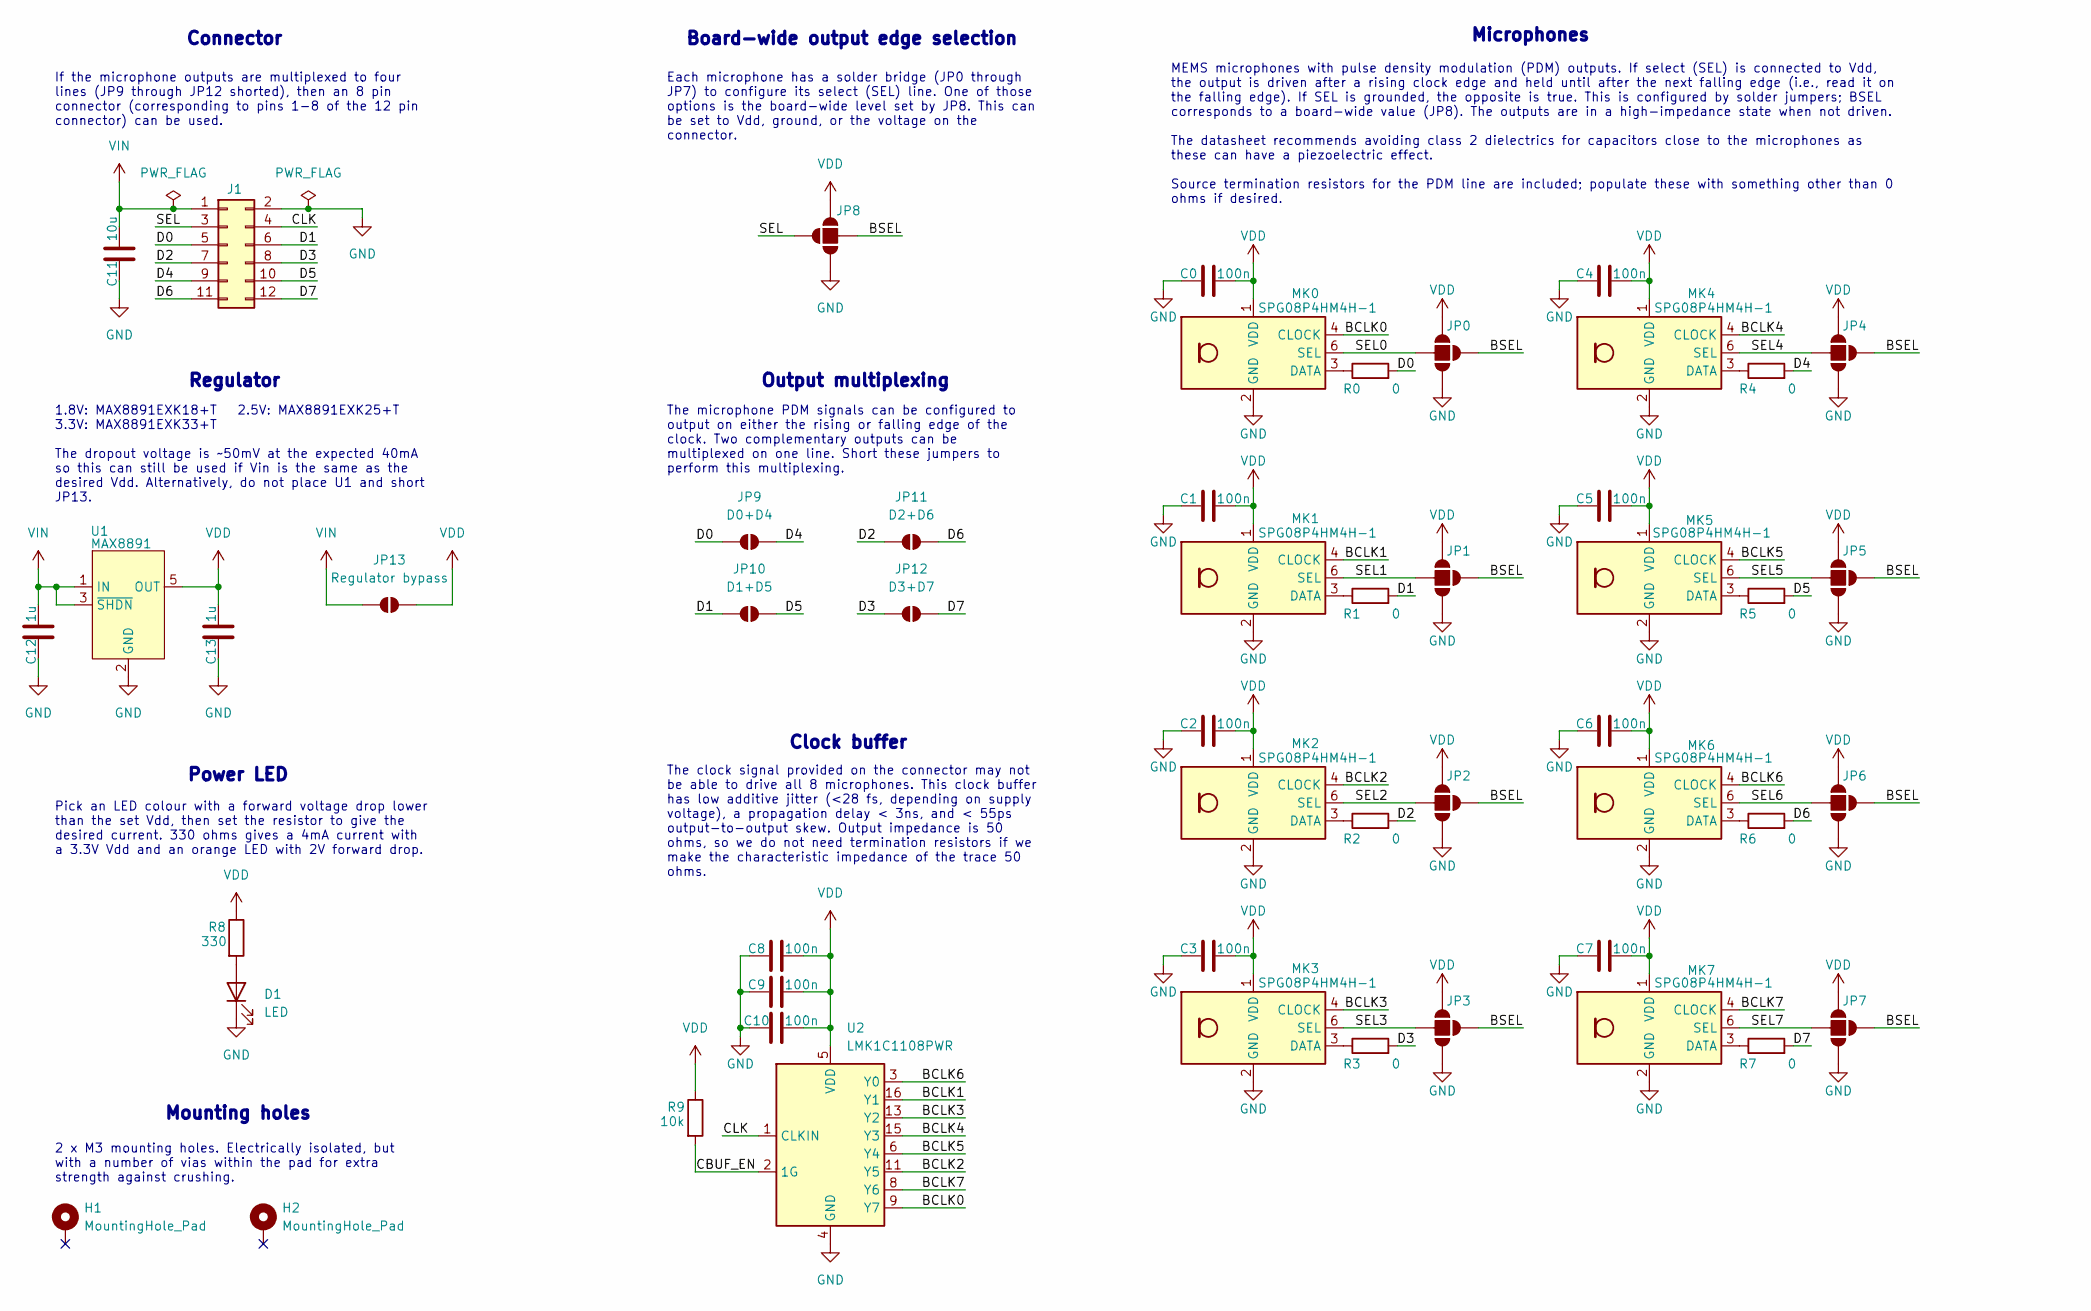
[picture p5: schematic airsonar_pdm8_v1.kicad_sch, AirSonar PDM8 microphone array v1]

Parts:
C0, C1, C2, C3, C4, C5, C6, C7, C8, C9, C10: 100n; C_0603_1608Metric_Pad1.08x0.95mm_HandSolder
C11: 10u; C_0603_1608Metric_Pad1.08x0.95mm_HandSolder
C12, C13: 1u; C_0603_1608Metric_Pad1.08x0.95mm_HandSolder
D1: LED; LED_0603_1608Metric
H1, H2: MountingHole_Pad; MountingHole_3.2mm_M3_Pad_Via
J1: Conn_02x06_Top_Bottom; IDC-Header_2x06_P2.54mm_Vertical_SMD
JP0: SEL0; SolderJumper-4-MicSelect
JP1: SEL1; SolderJumper-4-MicSelect
JP2: SEL2; SolderJumper-4-MicSelect
JP3: SEL3; SolderJumper-4-MicSelect
JP4: SEL4; SolderJumper-4-MicSelect
JP5: SEL5; SolderJumper-4-MicSelect
JP6: SEL6; SolderJumper-4-MicSelect
JP7: SEL7; SolderJumper-4-MicSelect
JP8: Board SEL; SolderJumper-4-BoardSelect
JP9: D0+D4; SolderJumper-2
JP10: D1+D5; SolderJumper-2
JP11: D2+D6; SolderJumper-2
JP12: D3+D7; SolderJumper-2
JP13: Regulator bypass; SolderJumper-2_P1.3mm_Open_RoundedPad1.0x1.5mm
MK0, MK1, MK2, MK3, MK4, MK5, MK6, MK7: SPG08P4HM4H-1; Knowles_SPG08P4HM4H-1_4x2mm
R0, R1, R2, R3, R4, R5, R6, R7: 0; R_0603_1608Metric_Pad0.98x0.95mm_HandSolder
R8: 330; R_0603_1608Metric_Pad0.98x0.95mm_HandSolder
R9: 10k; R_0603_1608Metric_Pad0.98x0.95mm_HandSolder
U1: MAX8891; SOT-353_SC-70-5_Handsoldering
U2: LMK1C1108PWR; TSSOP-16_4.4x5mm_P0.65mm

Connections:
/BCLK0: MK0.4 (CLOCK), U2.9 (Y7)
/BCLK1: MK1.4 (CLOCK), U2.16 (Y1)
/BCLK2: MK2.4 (CLOCK), U2.11 (Y5)
/BCLK3: MK3.4 (CLOCK), U2.13 (Y2)
/BCLK4: MK4.4 (CLOCK), U2.15 (Y3)
/BCLK5: MK5.4 (CLOCK), U2.6 (Y4)
/BCLK6: MK6.4 (CLOCK), U2.3 (Y0)
/BCLK7: MK7.4 (CLOCK), U2.8 (Y6)
/BSEL: JP0.3 (B), JP1.3 (B), JP2.3 (B), JP3.3 (B), JP4.3 (B), JP5.3 (B), JP6.3 (B), JP7.3 (B), JP8.1 (O)
/CBUF_EN: R9.2, U2.2 (1G)
/CLK: J1.4, U2.1 (CLKIN)
/D0: J1.5, JP9.1 (A), R0.2
/D1: J1.6, JP10.1 (A), R1.2
/D2: J1.7, JP11.1 (A), R2.2
/D3: J1.8, JP12.1 (A), R3.2
/D4: J1.9, JP9.2 (B), R4.2
/D5: J1.10, JP10.2 (B), R5.2
/D6: J1.11, JP11.2 (B), R6.2
/D7: J1.12, JP12.2 (B), R7.2
/SEL: J1.3, JP8.3 (B)
/SEL0: JP0.1 (O), MK0.6 (SEL)
/SEL1: JP1.1 (O), MK1.6 (SEL)
/SEL2: JP2.1 (O), MK2.6 (SEL)
/SEL3: JP3.1 (O), MK3.6 (SEL)
/SEL4: JP4.1 (O), MK4.6 (SEL)
/SEL5: JP5.1 (O), MK5.6 (SEL)
/SEL6: JP6.1 (O), MK6.6 (SEL)
/SEL7: JP7.1 (O), MK7.6 (SEL)
GND: C0.1, C1.1, C2.1, C3.1, C4.1, C5.1, C6.1, C7.1, C8.1, C9.1, C10.1, C11.1, C12.1, C13.1, D1.1 (K), J1.2, JP0.4 (C), JP1.4 (C), JP2.4 (C), JP3.4 (C), JP4.4 (C), JP5.4 (C), JP6.4 (C), JP7.4 (C), JP8.4 (C), MK0.2 (GND), MK0.5 (GND), MK1.2 (GND), MK1.5 (GND), MK2.2 (GND), MK2.5 (GND), MK3.2 (GND), MK3.5 (GND), MK4.2 (GND), MK4.5 (GND), MK5.2 (GND), MK5.5 (GND), MK6.2 (GND), MK6.5 (GND), MK7.2 (GND), MK7.5 (GND), U1.2 (GND), U2.4 (GND), U2.7 (GND), U2.12 (GND)
unnamed: D1.2 (A), R8.2
unnamed: MK0.3 (DATA), R0.1
unnamed: MK1.3 (DATA), R1.1
unnamed: MK2.3 (DATA), R2.1
unnamed: MK3.3 (DATA), R3.1
unnamed: MK4.3 (DATA), R4.1
unnamed: MK5.3 (DATA), R5.1
unnamed: MK6.3 (DATA), R6.1
unnamed: MK7.3 (DATA), R7.1
VDD: C0.2, C1.2, C2.2, C3.2, C4.2, C5.2, C6.2, C7.2, C8.2, C9.2, C10.2, C13.2, JP0.2 (A), JP1.2 (A), JP2.2 (A), JP3.2 (A), JP4.2 (A), JP5.2 (A), JP6.2 (A), JP7.2 (A), JP8.2 (A), JP13.2 (B), MK0.1 (VDD), MK1.1 (VDD), MK2.1 (VDD), MK3.1 (VDD), MK4.1 (VDD), MK5.1 (VDD), MK6.1 (VDD), MK7.1 (VDD), R8.1, R9.1, U1.5 (OUT), U2.5 (VDD), U2.10 (VDD), U2.14 (VDD)
VIN: C11.2, C12.2, J1.1, JP13.1 (A), U1.1 (IN), U1.3 (~SHDN)

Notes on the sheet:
Connector
Clock buffer
Output multiplexing
Power LED
Mounting holes
Microphones
Regulator
Board-wide output edge selection
The clock signal provided on the connector may not be able to drive all 8 microphones. This clock buffer has low additive jitter (<28 fs, depending on supply voltage), a propagation delay < 3ns, and < 55ps output-to-output skew. Output impedance is 50 ohms, so we do not need termination resistors i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
The microphone PDM signals can be configured to output on either the rising or falling edge of the clock. Two complementary outputs can be multiplexed on one line. Short these jumpers to perform this multiplexing.
Each microphone has a solder bridge (JP0 through JP7) to configure its select (SEL) line. One of those options is the board-wide level set by JP8. This can be set to Vdd, ground, or the voltage on the connector.
MEMS microphones with pulse density modulation (PDM) outputs. If select (SEL) is connected to Vdd, the output is driven after a rising clock edge and held until after the next falling edge (i.e., read it on the falling edge). If SEL is grounded, the opposite is true. This is configured by solder ju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
Pick an LED colour with a forward voltage drop lower than the set Vdd, then set the resistor to give the desired current. 330 ohms gives a 4mA current with a 3.3V Vdd and an orange LED with 2V forward drop.
2 x M3 mounting holes. Electrically isolated, but with a number of vias within the pad for extra strength against crushing.
1.8V: MAX8891EXK18+T 2.5V: MAX8891EXK25+T 3.3V: MAX8891EXK33+T The dropout voltage is ~50mV at the expected 40mA so this can still be used if Vin is the same as the desired Vdd. Alternatively, do not place U1 and short JP13.
If the microphone outputs are multiplexed to four lines (JP9 through JP12 shorted), then an 8 pin connector (corresponding to pins 1-8 of the 12 pin connector) can be used.

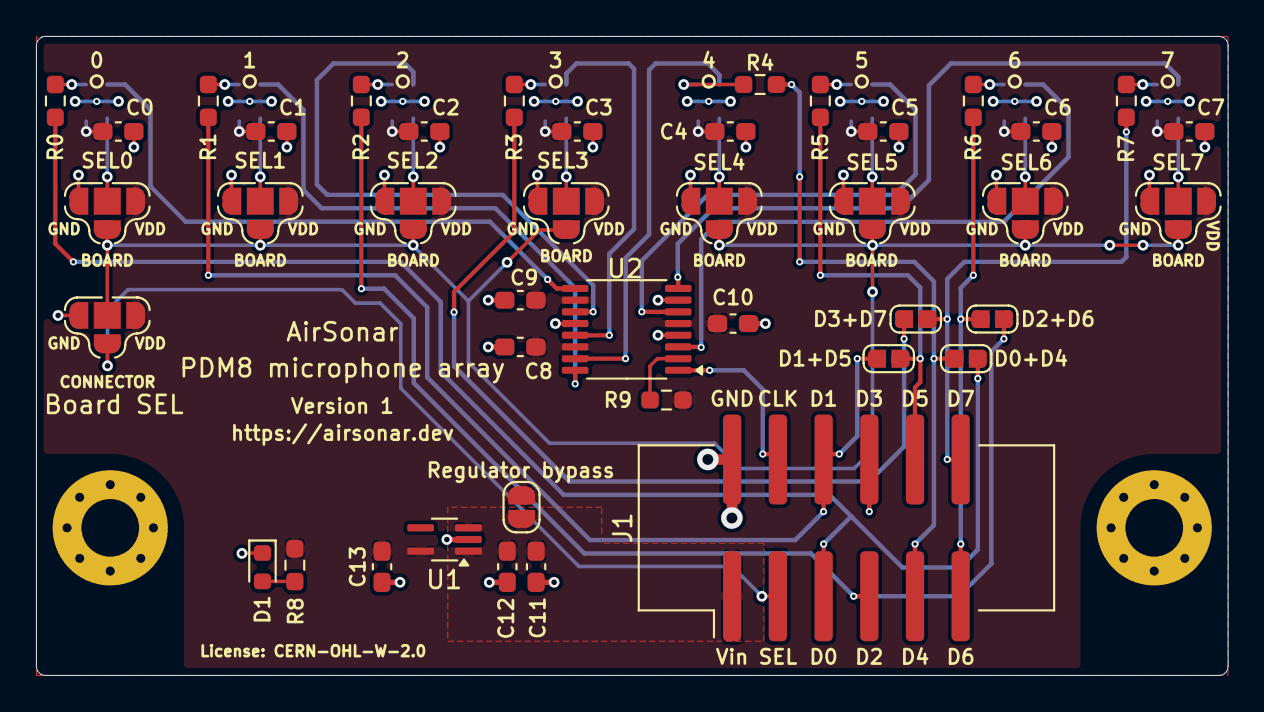
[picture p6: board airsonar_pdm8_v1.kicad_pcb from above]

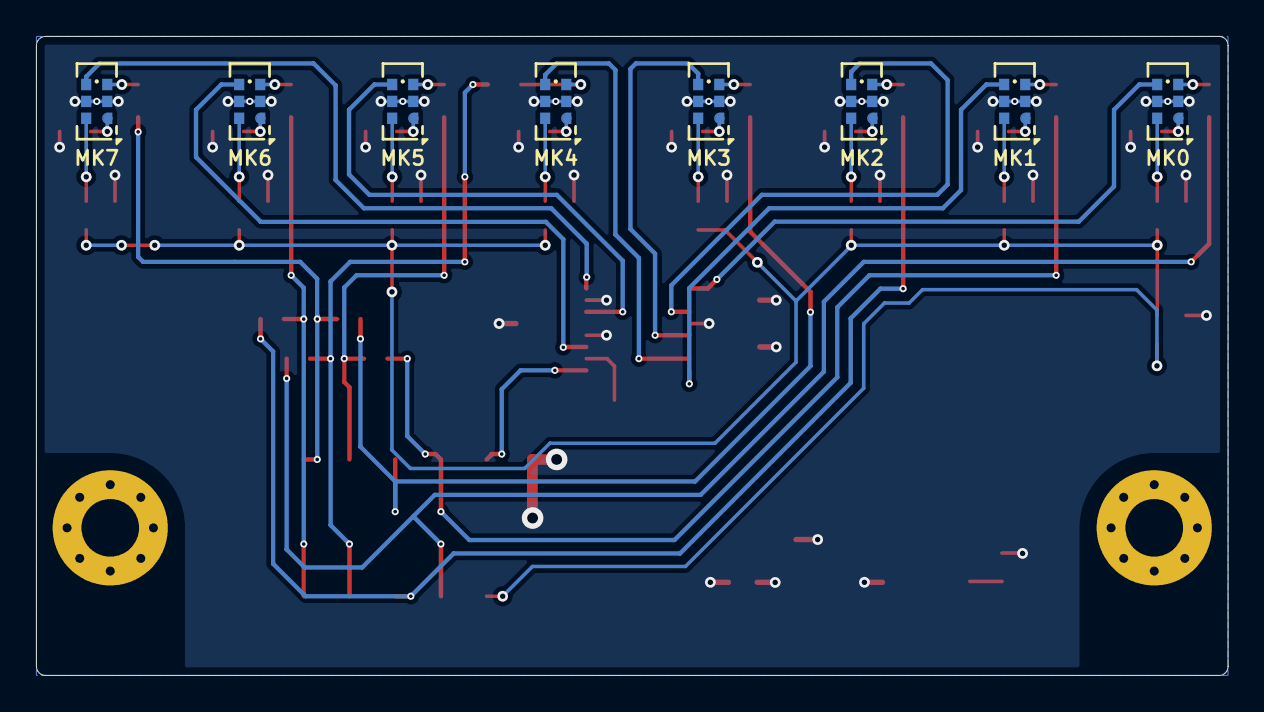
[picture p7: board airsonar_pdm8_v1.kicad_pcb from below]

Board: 4 copper layers, 66.2 x 35.5 mm, 52 parts (8 on the bottom side), 40 nets.

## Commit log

2026-04-17 Import KiCad libraries and templates.
2026-04-18 Import v1 of PDM8 microphone array
    [airsonar_pdm8_v1.kicad_pcb, airsonar_pdm8_v1.kicad_sch, airsonar_pdm8_v1_bom.csv]
2026-09-20 Import v2 of the Zybo Z7 I2C breakout.
    [zybo_z7_i2c_breakout_v2.kicad_pcb, zybo_z7_i2c_breakout_v2.kicad_sch]
2026-09-20 Import v1 of the Zybo Z7 PDM8 breakout
    [zybo_z7_pdm8_breakout_v1.kicad_pcb, zybo_z7_pdm8_breakout_v1.kicad_sch]

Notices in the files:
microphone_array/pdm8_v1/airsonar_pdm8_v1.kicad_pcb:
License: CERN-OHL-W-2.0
